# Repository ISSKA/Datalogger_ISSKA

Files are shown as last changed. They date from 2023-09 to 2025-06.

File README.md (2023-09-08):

# ISSKA Datalogger

A Datalogger is a device which controls the sensors and store their values with a given time step. This repository provides the design of several PCBs used for the dataloggers, as well as the codes of the dataloggers.

* The PCB folder contains all the different PCB design used
* The datalogger_code folder contains all the codes for the dataloggers.

For detailed informations about the working principle of a datalogger, code walkthrough and PCB design hints, please refer to the Datalogger Guide PDF.

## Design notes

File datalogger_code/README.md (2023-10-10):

# ISSKA Datalogger codes

This repository contains the different codes used on our dataloggers. There are two Arduino codes for the dataloggers, one for dataloggers with wireless transmission and one for datalogger without wireless transmission. These 2 Arduino codes do not depend on the sensors connected to the datalogger. 

* the simple_datalogger_code is the code with no wireless transmission
* the notecard_datalogger_code is the code with wireless transmission.

There are several different C++ files in the sensors_code folder which are all named Sensors.cpp. For each new sensor configuration, this C++ file must be modified. Refer to the Datalogger Guide pdf for more informations about the Sensors.cpp modifications for a new sensor.

The header file Sensors.h is the same for all codes.

Several different Sensors.cpp code are in the sensors_code folder, for different sensors configurations. All of these codes include the BMP581 and the SHT35 which are already on each PCB. 

## Upload a code on a TinyPico
* select the right Arduino code (wireless transmission or not) and take a Sensors.cpp file in the sensors_code folder for your application or modify one.
* Put the Arduino file (wireless or not), Sensors.cpp file (which you can find in the sensors_code folder) and Sensors.h file in a same folder.
* The folder  must have the name of the arduino file, minus the ".ino"
* Install the needed library on the arduino IDE.
* Connect the TinyPico with your computer and select the right port on Arduino IDE
* Click on the upload button

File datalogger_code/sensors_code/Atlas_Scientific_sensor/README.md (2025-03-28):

# Capteur ATLAS SCIENTIFIC

Les capteurs Atlas Scientific (https://atlas-scientific.com/) présente des particularités 
* I2C et UART. Ils peuvent fonctionner dans les 2 protocoles, mais globalement l'UART est plus robuste. De plus, il faut impérativement bloquer le capteur sur le protocole choisi avec la fonction "Plock,1"
* Il faut d'abord régler le capteur en UART avec le code de base pour les réglages. 

## Autre chose?

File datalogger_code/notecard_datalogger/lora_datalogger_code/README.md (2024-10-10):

# ISSKA Datalogger base code with a notecard LORA
Base code for datalogger with a Notecard connected to the TCA3 of the multiplexer. This code was rewritten in august 2024.

The conf.txt file must have the following structure:
```
300; //time step in seconds (put at least 240 seconds)
1; //boolean value to choose if you want to set the RTC clock with GSM time (recommended to put 1)
12; // number of measurements to be sent at once
```

To modify the time step or the number of measurements to send at once, add these command on the data.qi file of the device on notehub:

* {"time_step":300} ->this sets the time set to 300 seconds
* {"nb_meas":6} ->this sets the number of measurements sent at once to 6

If you have any questions contact me per email at eric.weber@isska.ch

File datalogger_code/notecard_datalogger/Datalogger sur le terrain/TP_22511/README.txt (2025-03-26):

#TP_22511
Installé le 18.05.22 à Milandre Bame avec MS8607 et MS5803-1. Notecard: Not_18
Les données sont envoyées sur le feed Milandre Bame de IoTPlotter

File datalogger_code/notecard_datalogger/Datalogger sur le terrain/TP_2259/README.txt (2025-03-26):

# TP_2259
Installé le 25.05.22 à CISA Anciens Moulins Puits 2 avec MS8607 et MS5803-1. Notecard: Not_20
Les données sont envoyées sur le CISA Anciens moulins de IoTPlotter

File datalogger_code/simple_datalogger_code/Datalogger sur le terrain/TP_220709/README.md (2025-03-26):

# Mesure les varations de la glace à Monlési

Ce datalogger a un capteur PHT MS8607 et deux capteurs de distance.

Capteur 1 : https://www.adafruit.com/product/4664
Capteur 2 : https://www.sparkfun.com/products/retired/14588

Le datalogger a été mis en place le 09.07.22 et l'interval de mesure est d'une heure.

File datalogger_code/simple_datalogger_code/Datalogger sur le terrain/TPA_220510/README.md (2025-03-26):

# TPA_22510
Installé le 11.05.2022 à CISA avec capteur SVM41 et MS8607
Désinstallé qq mois plus tard. 
Le capteur SVM41 n'est pas fonctionnel sous terre. Le temps de préchauffage est trop long.
Ce capteur a été enlevé et le datalogger a seulement le MS8607 pour le moment. 
Modif du RTC faite le 1.11.22 et datalogger renommé en TPA_22510.
Ajouté le capteur BMP581 pour la pression.

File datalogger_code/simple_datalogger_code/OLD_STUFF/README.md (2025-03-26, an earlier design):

# TinyPico Low Power Board
## Explications 
Le dossier TinyPico_datalogger contient le code principal du logger. 
Pour le faire fonctionner il faut ajouter, dans le même dossier que le script principal, les deux fichiers "sensors" qui sont dans les autres dossiers
Ces fichiers permettent de lire les différents capteurs en titre du dossier. 

Il faut donc faire un copier-coller des ces fichiers sensors suivant les capteurs qui se trouvent sur le datalogger. 

!!!ATTENTION!!! Le temps d'execution du code varie suivant les capteurs utilisés. Des corrections de temps peuvent être faites aux lignes 165 et 168 du code principal. Sinon, il est probable que le pas de temps de corresponde pas exactement au pas de temps choisi sur la carte SD.

## Montage
All manufacturing documents are available in the "manufacturing" folder.

### Passive components
TinyPico:
- Mosfet TN0702 : DRAIN on GND, GATE in pin 14 and source on GND rail

### Sensors connected to MUX
All sensors connected to MUX should have pull-ups enabled.

> By default, pull-ups on MS5803-01 are disabled !

## Configuration

### Sensors configuration
Rename file `Sensors.example.cpp` from directory `low_power_board` in `Sensors.cpp` and configure your sensors.

### Pas de temps entre les mesures
Pour définir le pas de temps entre les mesures, ajouter un fichier nommé `conf.txt` à la racine de la carte microSD. Son contenu doit être sous la forme `<pas de temps en secondes>;`, soit `15;` pour un pas de 15 secondes.

## Consommation
Consommation actuelle :
- Environ 150 uA en veille
- Environ 50 mA durant la phase de mesure

Calculateur de durée de fonctionnement : http://www.of-things.de/battery-life-calculator.php.

En prenant en compte que les mesures durent 5 s et qu'on a des pas de mesures de 15 min, la batterie tient environ 460 jours !

## Optimisations possibles
A voir

## Améliorations futures ?
A voir

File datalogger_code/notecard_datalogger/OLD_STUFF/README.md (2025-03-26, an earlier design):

# NoteCard_LTE_DataLogger
Datalogger with a notecard that sends data through LTE
# Description
The notecard sends the data to the notehub platform each time the MAX_MEASUREMENTS number is reached. The data are then routed to another platform called "IoTPlotter". A Python script is available to download the data from this platform.
# Sending of the data
All the data are sent to the notehub through a JSON object. The JSON library used in the arduino notecard library is the "n_cjson" library (available here: https://github.com/blues/note-c/blob/master/n_cjson.c). More explanation of this library and some examples can be found following this link https://github.com/DaveGamble/cJSON.
note: In the second link, cJSON_ is used before all methods. In the first link, this therm is substituted by J.

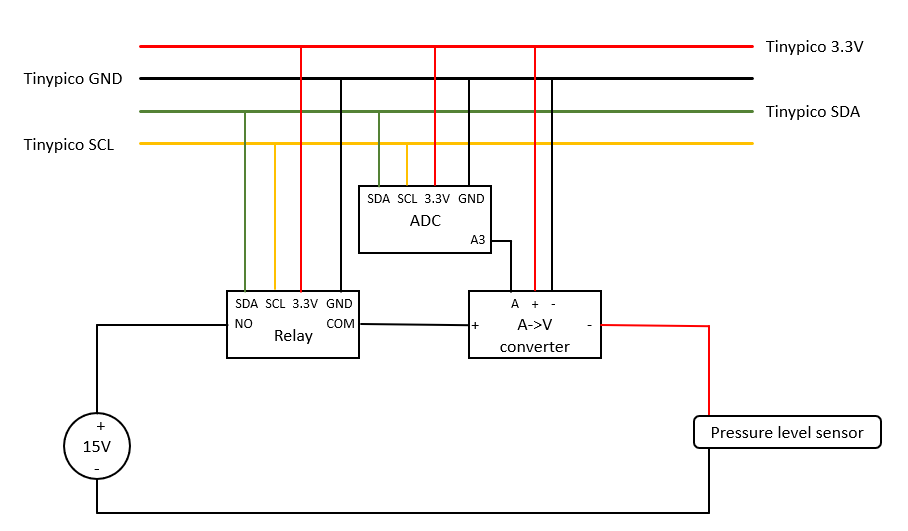
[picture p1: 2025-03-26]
datalogger_code/simple_datalogger_code/Datalogger sur le terrain/TPB_220823/img/schema.png

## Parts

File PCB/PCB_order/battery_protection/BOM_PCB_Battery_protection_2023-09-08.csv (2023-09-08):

ID | Name | Designator | Footprint | Quantity | Manufacturer Part | Manufacturer | Supplier | Supplier Part | Price
1 | 100nF | C3,C4 | C0402 | 2 | CL05B104KB54PNC | SAMSUNG(三星) | LCSC | C307331 | 0.007
2 | 100Ω | R1,R4 | R1206 | 2 | 1206W4F1000T5E | UNI-ROYAL(厚声) | LCSC | C17901 | 0.003
3 | 1kΩ | R2,R3 | R1206 | 2 | 1206W4F1001T5E | UNI-ROYAL(厚声) | LCSC | C4410 | 0.003
4 | DW01_C917079 | U2,U5 | SOT-23-6_L2.9-W1.6-P0.95-LS2.8-BL | 2 | DW01 | JSMSEMI(杰盛微) | LCSC | C917079 | 0.035
5 | 8205A_C5148694 | U3,U4 | TSSOP-8_L4.4-W3.0-P0.65-LS6.4-BL | 2 | 8205A | HXY MOSFET(华轩阳电子) | LCSC | C5148694 | 0.061
6 | BH-18650-B1BA002 | BT1,BT2,BT3 | BATTERY-SMD_18650-1S-L77.1-W20.7-1 | 3 | BH-18650-B1BA002 | MYOUNG(美阳) | LCSC | C2988620 | 1.206

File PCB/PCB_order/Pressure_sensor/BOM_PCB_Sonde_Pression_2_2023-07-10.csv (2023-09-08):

ID | Name | Designator | Footprint | Quantity | Manufacturer Part | Manufacturer | Supplier | Supplier Part | Price
1 | 10uF | C1,C2 | C0805 | 2 | CL21A106KAYNNNE | SAMSUNG(三星) | LCSC | C15850 | 0.011
2 | 10kΩ | R1,R2 | R0805 | 2 | 0805W8F1002T5E | UNI-ROYAL(厚声) | LCSC | C17414 | 0.001
3 | MS5837-02BA | U3 | LGA-4_L3.3-W3.3-P2.00-TL | 1 | MS5837-02BA | null | LCSC | C2887129
4 | AP2112K-3.3TRG1 | U2 | SOT-25-5_L2.9-W1.6-P0.95-LS2.8-BL | 1 | AP2112K-3.3TRG1 | DIODES(美台) | LCSC | C51118 | 0.103

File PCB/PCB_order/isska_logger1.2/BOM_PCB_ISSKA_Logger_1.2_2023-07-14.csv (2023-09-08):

ID | Name | Designator | Footprint | Quantity | Manufacturer Part | Manufacturer | Supplier | Supplier Part | Price
1 | 2.2uF | C1,C6 | C0402 | 2 | CL05A225MQ5NSNC | SAMSUNG(三星) | LCSC | C12530 | 0.003
2 | 10uF | C3,C2 | C1206 | 2 | CL31A106KBHNNNE | SAMSUNG(三星) | LCSC | C13585 | 0.033
3 | 49.9kΩ | R3,R5,R6,R7,R10,R11,R12 | R0402 | 7 | 0402WGF4992TCE | UNI-ROYAL(厚声) | LCSC | C25897 | 0.001
4 | SHT35-DIS-F2.5KS | 0X44 | DFN-8_L2.5-W2.5-P0.50-TL-EP-SHT3X-DIS | 1 | SHT35-DIS-F2.5KS | Sensirion | Digi-Key | 1649-1067-1-ND
5 | BMP581 | 0X46 | BMP581 | 1 | BMP581 | Bosch | Digi-Key | BMP581CT-ND
6 | TCA9548APWR | 0X73 | TSSOP-24_L7.8-W4.4-P0.65-LS6.4-BL | 1 | TCA9548APWR | TI(德州仪器) | LCSC | C130026 | 0.926
7 | CR1220-2ZX | BT1 | BAT-SMD_CR1220-2ZX | 1 | CR1220-2ZX | Q&J | LCSC | C969906 | 0.238
8 | 100uF | C4 | C1206 | 1 | CL31A107MQHNNNE | SAMSUNG(三星) | LCSC | C15008 | 0.062
9 | TF-01A | CARD1 | TF-SMD_TF-01A | 1 | TF-01A | 韩国韩荣 | LCSC | C91145 | 0.175
10 | PowerScrew | CN1 | CONN-TH_XY308-2.54-8P | 1 | XY308-2.54-8P | XINLAIYA(新莱亚) | LCSC | C915917 | 0.741
11 | I2Cscrew | CN2 | CONN-TH_XY308-2.54-8P | 1 | XY308-2.54-8P | XINLAIYA(新莱亚) | LCSC | C915917 | 0.741
12 | QWIIC SENS | CN3,CN4,CN7 | CONN-SMD_X1002WRS-04L-HF-LPSN | 3 | X1002WRS-04L-HF-LPSN | XKB Connectivity(中国星坤) | LCSC | C400341 | 0.11
13 | QWIIC NOT | CN5 | CONN-SMD_X1002WRS-04L-HF-LPSN | 1 | X1002WRS-04L-HF-LPSN | XKB Connectivity(中国星坤) | LCSC | C400341 | 0.11
14 | JST-PH | CN6 | CONN-SMD_P2.00_S2B-PH-SM4-TB-LF-SN | 1 | S2B-PH-SM4-TB(LF)(SN) | JST | LCSC | C295747 | 0.181
15 | 1N4002W | D1,D2 | SOD-123F_L2.8-W1.8-LS3.7-RD | 2 | 1N4002W | 晶导微电子 | LCSC | C169542 | 0.006
16 | OLED | H1 | HDR-TH_4P-P2.54-V-F | 1 | PM2.54-1*4 | ZHOURI(洲日) | LCSC | C5116530 | 0.072
17 | 22uH | L2 | IND-SMD_L3.2-W2.5 | 1 | NLCV32T-220K-EF | TDK | LCSC | C250233 | 0.042
18 | AO3406 | Q1,Q2 | SOT-23-3_L2.9-W1.6-P1.90-LS2.8-BR | 2 | AO3406 | AOS | LCSC | C88051 | 0.112
19 | 10kΩ | R1,R2,R4,R8,R9,R13,R14,R15,R16 | R0805 | 9 | 0805W8F1002T5E | UNI-ROYAL(厚声) | LCSC | C17414 | 0.001
20 | PM254-1-10-Z-8.5 | TINY_LEFT,TINY_RIGHT | HDR-TH_10P-P2.54-V-F | 2 | PM254-1-10-Z-8.5 | HCTL(华灿天禄) | LCSC | C2897373 | 0.152
21 | ME2188C50M5G | U7 | SOT-23-5_L3.0-W1.7-P0.95-LS2.8-BR | 1 | ME2188C50M5G | MICRONE(南京微盟) | LCSC | C236768 | 0.074
22 | NotcardPower | U3 | CONN-TH_DB125-2.54-2P-GN | 1 | DB125-2.54-2P-GN-S | DIBO(地博电气) | LCSC | C918120 | 0.194
23 | RX-TX | U5 | CONN-TH_DB125-2.54-2P-GN | 1 | DB125-2.54-2P-GN-S | DIBO(地博电气) | LCSC | C918120 | 0.194
24 | SCL-SDA | U6 | CONN-TH_DB125-2.54-2P-GN | 1 | DB125-2.54-2P-GN-S | DIBO(地博电气) | LCSC | C918120 | 0.194
25 | 5VPower | U8 | CONN-TH_DB125-2.54-2P-GN | 1 | DB125-2.54-2P-GN-S | DIBO(地博电气) | LCSC | C918120 | 0.194
26 | DS3231SN# | U4 | SOIC-16_L10.3-W7.5-P1.27-LS10.3-BL | 1 | DS3231SN#T&R | MAXIM(美信) | LCSC | C9866 | 3.37

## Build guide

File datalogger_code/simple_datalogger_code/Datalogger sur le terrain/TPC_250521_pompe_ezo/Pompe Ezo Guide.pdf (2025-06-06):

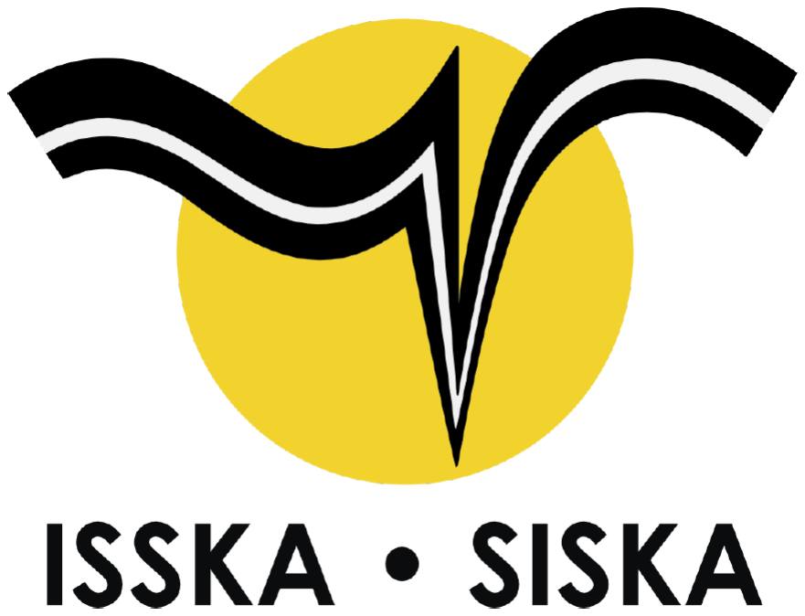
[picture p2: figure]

Swiss Institute for Speleology and Karst Studies

Ezo Pump Integration Guide: Configuration, Usage,

## and Logic

For Automated Dosing Based on Water Height

by

## Marius Audenis

A report made during my civil service at ISSKA, to explain the configuration and usage of the tracer injection pump system and to support future use or modification.

June 02, 2025

## Contents

1 Introduction | 2
2 Setup and Integration | 2
3 Pump Operation Overview | 3
4 Pump Communication Protocol | 4
5 Pump Class Internals | 5

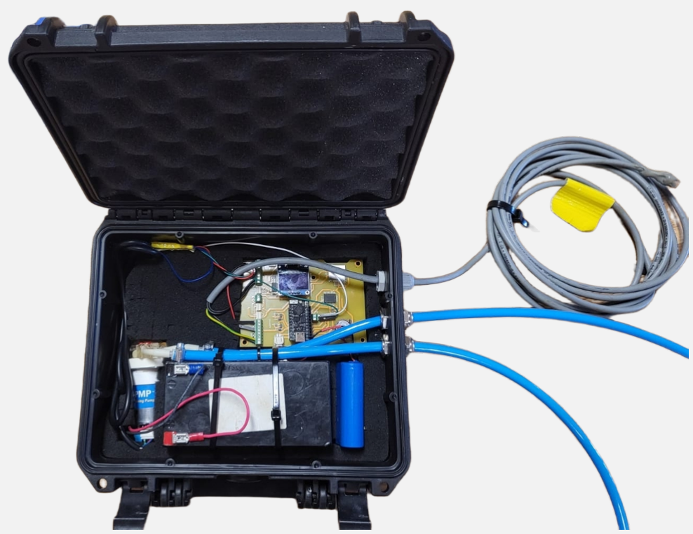
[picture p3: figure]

EZO™ PMP embedded dosing pump integrated with ISSKA datalogger

## 1 Introduction

This guide explains how to integrate and operate the Pump class to control an EZO-PMP™ embed-

ded dosing pump from Atlas Scientific. The class is designed for use on the ISSKA dataloggers code, running on a TinyPICO microcontroller. It automates fluid injection based on measured water heights.

This guide covers physical wiring, configuration files, injection logic, pump communication, and class internals.

## 2 Setup and Integration

### 2.1 Required Files on the SD Card

The pump module relies on two key files stored on the SD card. These files define the injection logic and log pump activity.

- /pump.txt — This file must be added on the datalogger SD card to define injection behavior

and threshold logic.

Each line specifies a water height range, a tracer dose in centimeters, and a maximum number of allowable injections for that range. The format is:

<min_height>-<max_height>,<dose_mL>,<max_injections>;

Example:

30-50,150,2;

50-70,200,1;

This means:

– Inject 150 mL if water height is between 30–50 cm (up to 2 times)

– Inject 200 mL if water height is between 50–70 cm (up to once)

- /pumpdata.csv — Logs pump status and injection history. This file is automatically created

during the pump initialisation and filled at each boot.

Each entry tracks the system boot ID, injection status, and the cumulative number of injections performed. The format is:

<boot_id>;<status>;<cumulative_injections>

Example:

56;Injected;3

57;*OFF;3

Injected indicates an injection occurred during this boot cycle.

*OFF means no injection occurred.

The last field tracks total injections across reboots.

### 2.2 Code Integration Steps

To integrate the Pump class with your datalogger, follow these steps:

1. Include the header and declare the pump object in main.cpp:

#include "Pump.h"

Pump pump;

2. Initialize the pump in setup() after setting up serial communication:

Serial2.begin(9600, SERIAL_8N1, rx, tx);

pump.configure(time_step);

3. Make water height globally accessible in Sensors.cpp (top of file):

float measuredWaterheight = 0.0;

4. Call pump logic after measuring sensors:

measure_all_sensors();

pump.handleInjections2(bootCount, time_step);

## 3 Pump Operation Overview

The pump automates fluid injections depending on water height. The system is designed to inject a specific volume of tracer based on predefined water height classes. Each class corresponds to a range of measured water heights (e.g., 10–20 cm) and is associated with a configurable injection dose (e.g., 5 ml). To ensure balanced tracer distribution, each class also has a limited number of

allowable injections, preventing all the tracer from being delivered within a single height range. All three parameters —the height classes, corresponding doses, and the number of injections— are fully configurable via the system’s configuration file. Also, to maintain injection accuracy, the system enforces cooldown periods between injections (default: 3 hours) to prevent mixing of tracer doses,

which could skew measurement results.

The injection logic is as follows:

1. Maintains a moving average of the last 5 measured water heights.
2. If we are not in a cooldown period (there hasn’t been any injection for more than 3 hours),

it:

- Iterates through doseTable, a variable stored in RTC memory (to survive deepsleep)

containing the height classes, their corresponding injection doses and number of injections.

- If the average water height falls within a defined range and remaining injections for that

class are available:

– Sends a command (e.g., D,150˚) to the pump.

– Enters a cooldown period.

– Decrements the injection count for the corresponding range.

3. If injection is disabled, increments the internal cooldown counter, and once the counter exceeds the threshold (default: every 3 hours), injection is possible again.
4. Logs the current injection status and cumulative injection count to /pumpdata.csv.

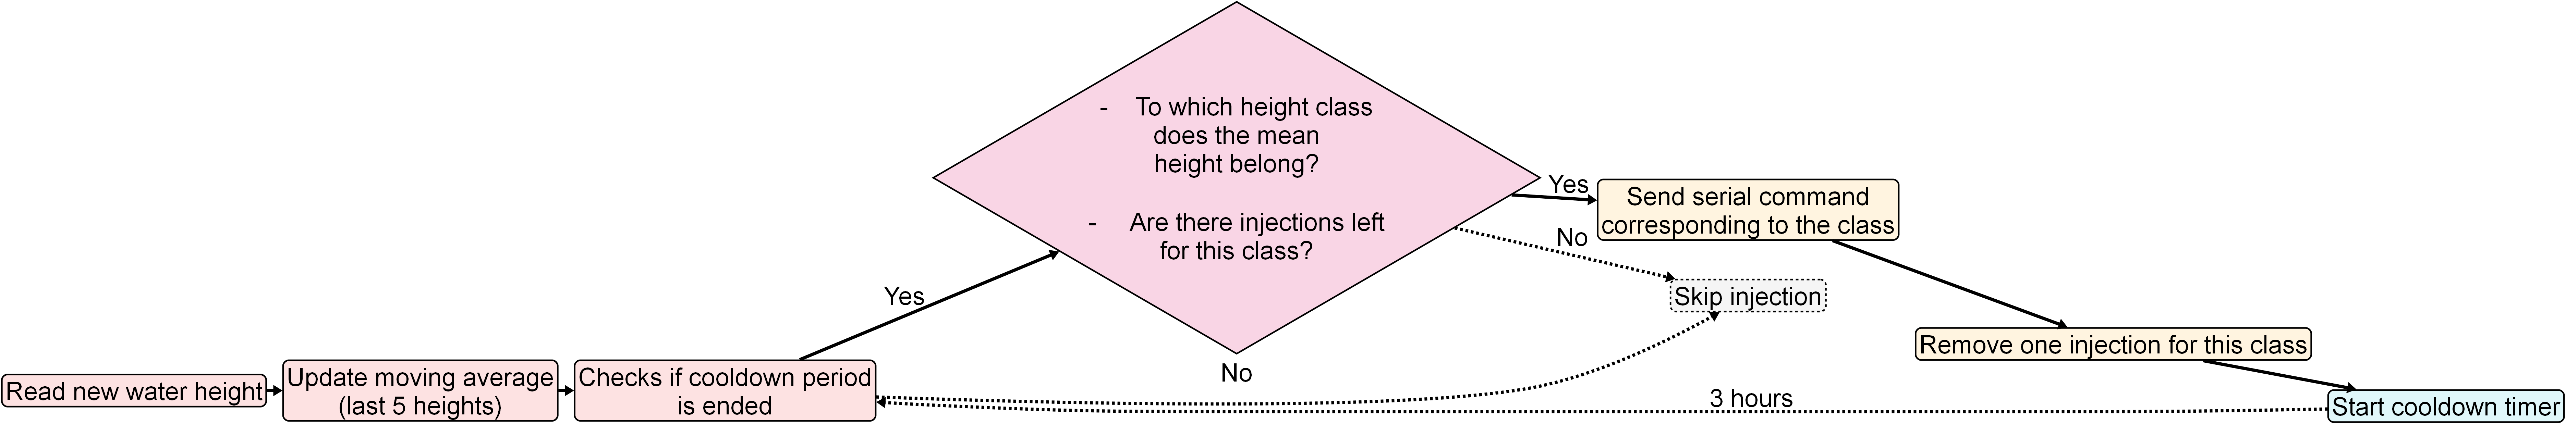
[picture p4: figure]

Figure 1: Schematic workflow of the pump’s logic

## 4 Pump Communication Protocol

The pump communicates over a UART serial interface. All technical details are available in the EZO-PMPTM Embedded Dosing Pump Manual, (https://files.atlas-scientific.com/EZO_PMP_Datasheet.pdf) but key parameters and behaviors are summarized

below:

- Baud rate: 9600
- Command format: D,<dose in mL>\r
- Example command: D,150˚
- Response codes:

– *DONE — Injection completed successfully

– *WA — Injection skipped (already performed)

– *ER — Error occurred during injection

– Timeout — No response received (this one is a custom response added in the code)

## 5 Pump Class Internals

This section explains the internal workings of the Pump class to support customization or debugging.

Core Workflow Functions

configure(int& time step) Initializes the pump system at startup:

- Reads dose rules from /pump.txt and parses them into a class table.
- Sends test signals to verify pump connection.
- Initializes the CSV log with headers.
- Computes boot step based on injection interval.
- Sends an initial test command to the pump.

handleInjections2(int& bootCount, int& time step) Called during each measurement cycle:

- Maintains a moving average over the last 5 water height readings.
- Checks if the current height matches a dosing class.
- Verifies cooldown and injection count limits.
- Sends dose command if permitted.
- Logs the injection result to /pumpdata.csv.

save in SD(int& bootCount) Appends the current injection status and pump count to /pumpdata.csv.

Serial Communication and Pump Control

sendCommand(const String& command) Sends a dosing command to the pump:

- Transmits the command via Serial2 with a carriage return.
- Waits for valid responses: *DONE, *WA, etc.
- Handles errors using handleError() and timeouts.
- Calls pumpSleep() after completion.

readPumpResponse() Reads characters from the serial buffer until a newline or timeout (15 seconds).

- Resets timer on each received byte.

- Returns the trimmed response or Timeout if no response.

handleError(String& response) Interprets and logs error messages:

- Logs *ER or Timeout, and may send a reset command.
- Extracts partial error strings from unknown responses.
- Stores error in latestErrorMessage.

pumpSleep() Sends the Sleep command:

- Waits for *SL confirmation.
- Handles communication errors or timeouts.

Optional Display and Debug Tools

displayConfiguration(U8X8& display) Displays the current dosing table on an OLED screen:

- Shows lower/upper class limits, dose values, and injection counts.
- Pages output every 6 entries to fit screen.

latestErrorMessage A string holding the latest pump response or error (e.g., *DONE, Timeout).

Useful for diagnostics and logging.

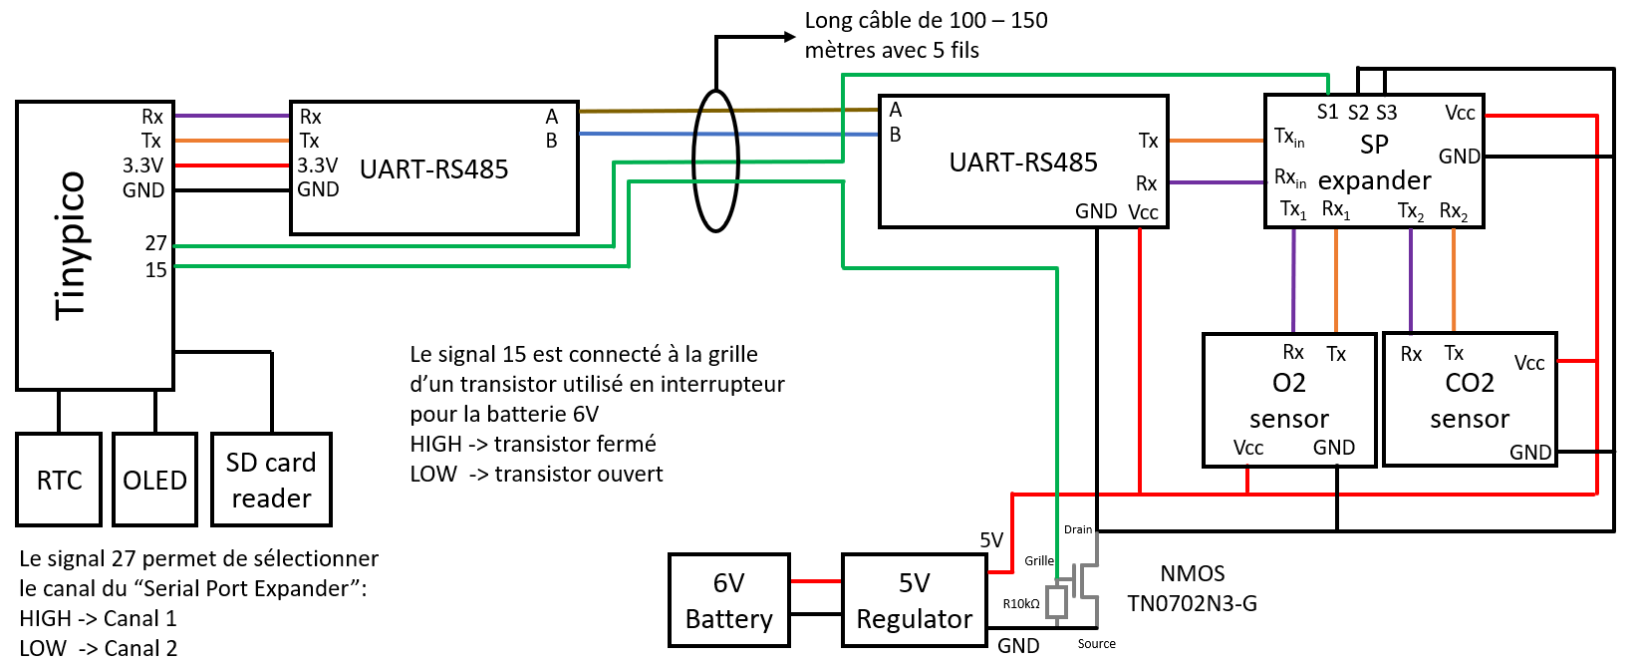
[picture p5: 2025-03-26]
datalogger_code/notecard_datalogger/Datalogger sur le terrain/TP_220921/CO2_O2_RS485/img/MontageV2.png

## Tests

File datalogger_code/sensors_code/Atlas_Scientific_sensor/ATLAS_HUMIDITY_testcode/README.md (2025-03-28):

# Humidité

Pour ce capteur il faut activer la température et le dewPoint avec les fonctions ad-oc sinon il peut arriver qu'il ne mesure que l'humidité

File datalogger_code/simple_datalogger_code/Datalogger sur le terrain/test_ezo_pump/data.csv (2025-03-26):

ID | DateTime | Vbatt | tempSHT | humSHT | tempBMP | pressBMP | flow_rate | tempWater
1 | 31/01/2025 16:15:00 | 4.13 | 28.25 | 27.50 | 27.90 | 908.51 | -0.47 | 22.53
2 | 31/01/2025 16:20:00 | 4.13 | 28.22 | 27.50 | 27.83 | 908.49 | 4.45 | 22.55
3 | 31/01/2025 16:25:00 | 4.14 | 28.24 | 27.38 | 27.82 | 908.51 | -0.16 | 22.60
4 | 31/01/2025 16:30:00 | 4.14 | 28.05 | 27.47 | 27.82 | 908.51 | 3.62 | 22.56
5 | 31/01/2025 16:35:00 | 4.14 | 28.15 | 27.55 | 27.81 | 908.49 | 1.07 | 22.60
6 | 31/01/2025 16:40:00 | 4.13 | 28.25 | 27.48 | 27.83 | 908.48 | 1.09 | 22.56
7 | 31/01/2025 16:45:00 | 4.13 | 28.22 | 27.36 | 27.83 | 908.43 | 6.51 | 22.64
8 | 31/01/2025 16:50:00 | 4.13 | 28.22 | 27.26 | 27.85 | 908.44 | 3.59 | 22.64
9 | 31/01/2025 16:55:00 | 4.13 | 28.28 | 27.34 | 27.83 | 908.49 | 0.39 | 22.58
10 | 31/01/2025 17:00:00 | 4.14 | 28.19 | 27.43 | 27.84 | 908.44 | 1.54 | 22.52
11 | 31/01/2025 17:05:00 | 4.13 | 28.21 | 27.69 | 27.84 | 908.41 | 1.56 | 22.60
12 | 31/01/2025 17:10:00 | 4.13 | 28.31 | 27.50 | 27.82 | 908.36 | -0.28 | 22.56
13 | 31/01/2025 17:15:00 | 4.13 | 28.14 | 27.24 | 27.85 | 908.32 | -0.49 | 22.58
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

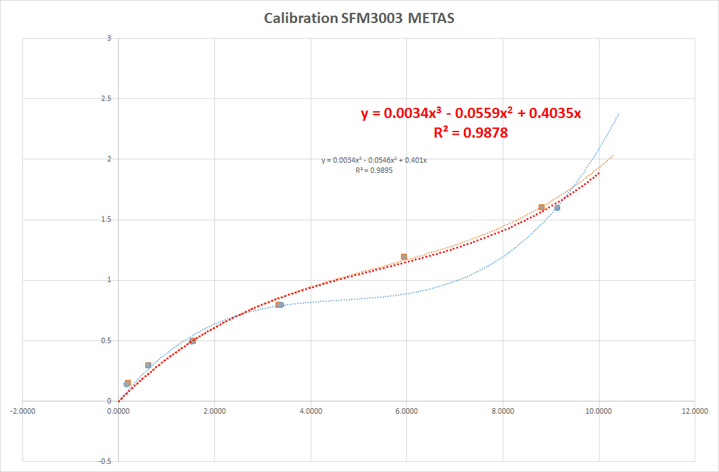
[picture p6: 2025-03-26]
datalogger_code/simple_datalogger_code/Datalogger sur le terrain/TPC_250408_SFM3003_Italie/Calibration_SFM.jpg

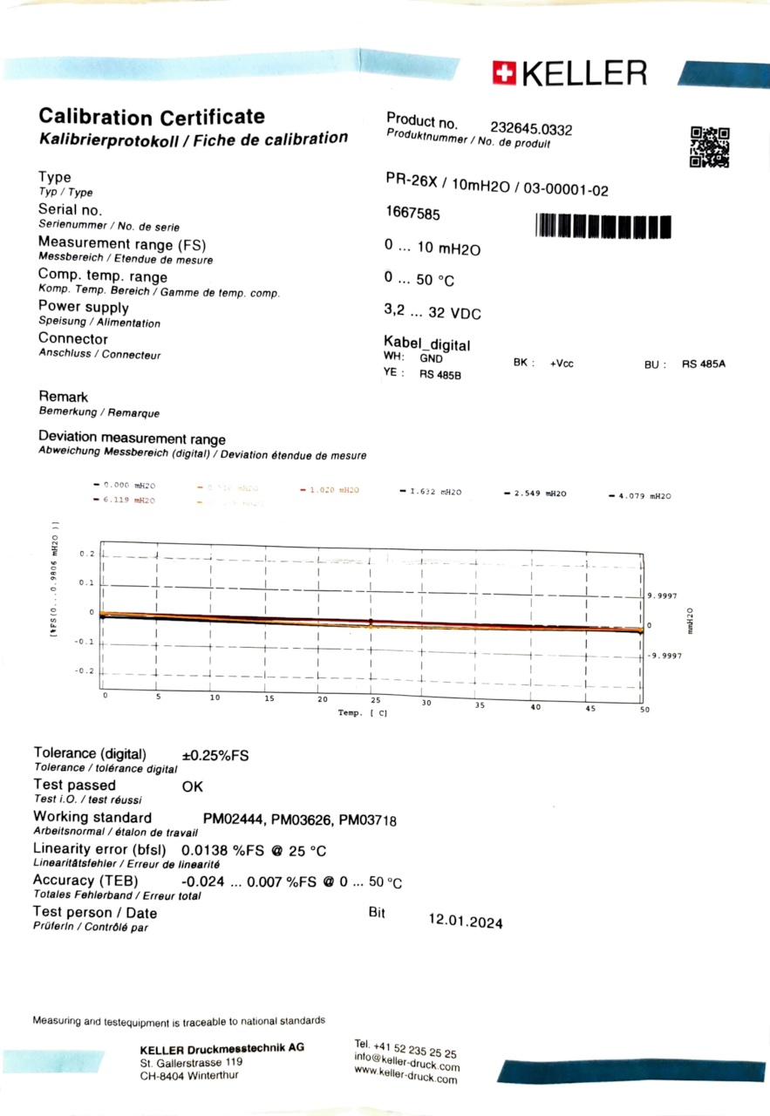
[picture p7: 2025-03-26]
datalogger_code/notecard_datalogger/Datalogger sur le terrain/TPC_240430_Keller_26X_120m/Certificat_calibration_Keller26X.jpg

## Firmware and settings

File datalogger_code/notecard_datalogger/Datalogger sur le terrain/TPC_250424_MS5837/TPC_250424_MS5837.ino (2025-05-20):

/* *******************************************************************************
Base code for datalogger with a Notecard connected to the TCA3 of the multiplexer. This code was rewritten in august 2023.

The conf.txt file must have the following structure:
  300; //time step in seconds (put at least 240 seconds)
  1; //boolean value to choose if you want to set the RTC clock with GSM time (recommended to put 1)
  12; // number of measurements to be sent at once

To modify the time step or the number of measurements to send at once, add these command on the data.qi file of the device on notehub:
{"time_setp":300} ->this sets the time set to 300 seconds
{"nb_meas":6} ->this sets the number of measurements sent at once to 6

If you have any questions contact me per email at nicolas.schmid.6035@gmail.com
**********************************************************************************
*/  

#include <Wire.h>
#include <TinyPICO.h>
#include <RTClib.h>
#include <SD.h>
#include <U8x8lib.h>
#include "Sensors.h" //file sensor.cpp and sensor.h must be in the same folder¨
#include <Notecard.h>

TinyPICO tp = TinyPICO();
RTC_DS3231 rtc; 
U8X8_SSD1306_128X64_NONAME_HW_I2C u8x8(/* reset=*/ U8X8_PIN_NONE); //initialise something for the OLED display
Sensors sensor = Sensors();
Notecard notecard;

//PINS to power different devices
#define Enable5VPIN 25 //turns the 3V to 5V converter on if switched to high
#define MOSFET_SENSORS_PIN 14 //pin which controls the power of the sensors, the screen and sd card reader
#define MOSFET_NOTECARD_PIN 4 //pin which controls the power of the notecard
#define NOTECARD_I2C_MULTIPLEXER_CHANNEL 3 //channel of the multiplexer to which the notecard is connected

#define myProductID "com.gmail.ouaibeer:datalogger_isska" //for the notecard to know with which hub to connect

//SD card
#define SD_CS_PIN 5//Define the pin of the tinypico connected to the CS pin of the SD card reader
#define DATA_FILENAME "/data.csv"
#define CONFIG_FILENAME "/conf.txt"

//Variables which must be stored on the RTC memory, to not be erease in deep sleep (only about 4kB of storage available)
RTC_DATA_ATTR int bootCount_since_change = 0; //boot count since external change from notehub
RTC_DATA_ATTR int bootCount = 0;
RTC_DATA_ATTR bool first_time = true;
RTC_DATA_ATTR int start_time; 
RTC_DATA_ATTR int start_date_time[6]; //[year,month,day,hour,minute,second] of the starting time
RTC_DATA_ATTR int time_step;
RTC_DATA_ATTR int nb_meas_sent_at_once; //number of measurements sent at once with the notecard
RTC_DATA_ATTR bool SetRTC; //read this value from the conf.txt file on the SD card. True means set the clock time with GSM signal
RTC_DATA_ATTR int failed_sync_count = 0;

//********************** MAIN LOOP OF THE PROGRAMM *******************************
//The setup is recalled each time the micrcontroller wakes up from a deepsleep
void setup(){ 

  //Start serial communication protocol with external devices (e.g. your computer)
  Serial.begin(115200);

  power_external_device();

  Wire.begin(); // initialize I2C bus 
  Wire.setClock(50000); // set I2C clock frequency to 50kHz

  if(first_time){ //this snipet is only executed when the microcontroller is turned on for the first time
    tp.DotStar_SetPower(true); //This method turns on the Dotstar power switch, which enables the tinypico LED
    tp.DotStar_SetPixelColor(25, 25, 25 ); //Turn the LED white while SD card is not initialised

    //write Init on the display
    u8x8.begin();
    u8x8.setBusClock(50000); //Give the I2C frequency information to the display
    u8x8.setFont(u8x8_font_amstrad_cpc_extended_r); //set the font
    u8x8.setCursor(0, 0);
    u8x8.print("Init...");
    Serial.println("Init...");

    delay(2000); //wait 2 seconds to see the led and the screen 

    initialise_SD_card(); //read conf.txt file values and store them on RTC memory to access them rapidely, write header on data.csv

    //initialise the RTC clock
    rtc.begin();
    rtc.disable32K(); //The 32kHz output is enabled by default. We don't need it so we disable it
    if (SetRTC) set_RTC_with_GSM_time(); //also gives the number of bars of cellular network (0 to 4) 

    put_usefull_values_on_display(); // show RTC time, battery voltage, time step and sensors values on the display

    get_next_rounded_time(); //this finds the next rounded time and puts it as starting time
    first_time = false; //to make the initialization only once
    deep_sleep_mode(0); //deep sleep until starting time 
  }

  else{ //normal operation (called everytime but not the first time)
    bootCount++; //update how many times we have booted the microcontroller
    bootCount_since_change++; //update how many times we have booted the microcontroller since there was a change of parameters sent from notehub
    Serial.print("***********Starting the card, Boot count: ");
    Serial.print(bootCount);
    Serial.println(" ***********************");

    Serial.print("Boot count since change: ");
    Serial.println(bootCount_since_change);
    Serial.print("Start time: ");
    Serial.println(start_time);
    
    //setup for the clock
    rtc.begin();
    rtc.disable32K(); //The 32kHz output is enabled by default. We don't need it so we disable it
    readRTC();//print current time

    if (bootCount<=3){ //Turn the LED blue during first 3 measurements ( only to check that the logger works normally)
      tp.DotStar_SetPower(true);
      tp.DotStar_SetPixelColor(0, 0, 25 ); 
    }

    mesure_all_sensors();

    if (bootCount_since_change%nb_meas_sent_at_once == 0){ //after a number nb_meas_sent_at_once of measurements, send the last few stored measurements over GSM
      send_data_overGSM();
    }

    if(tp.GetBatteryVoltage()>3.2){
      deep_sleep_mode(time_step);
    }
    else{
      deep_sleep_mode(60*60*24*365*10); //sleep during ten years (don't wake up) to avoid damaging the battery
    }
  }
}

void loop(){ //No loop is used 
}

void power_external_device(){
  //Turn on Pin to control the gate of MOSFET for all the sensors, display and microSD card(turned on)
  pinMode(MOSFET_SENSORS_PIN, OUTPUT);
  digitalWrite(MOSFET_SENSORS_PIN, HIGH);

  //Pin to control the gate of MOSFET for notecard (turned off)
  pinMode(MOSFET_NOTECARD_PIN, OUTPUT);
  digitalWrite(MOSFET_NOTECARD_PIN, LOW);
}

void put_usefull_values_on_display(){
 
  //Display Vattery voltage
  float batvolt = tp.GetBatteryVoltage();
  u8x8.display(); // Power on the OLED display
  u8x8.clear();
  u8x8.setCursor(0, 0);
  u8x8.print("Batt: ");
  u8x8.print(batvolt);
  u8x8.print("V");

  //Display current time on RTC
  u8x8.setCursor(0, 2);
  u8x8.print(readRTC());

  //Display value of timestep read on conf.txt
  u8x8.setCursor(0, 4);
  u8x8.print("timestep: ");
  u8x8.print(time_step);
  u8x8.print("s");

  //Display value of nuber of measurements to be sent at once read on conf.txt
  u8x8.setCursor(0, 6);
  u8x8.print("Nb meas: ");
  u8x8.print(nb_meas_sent_at_once);

  delay(4000);

  //Display sensor values
  sensor.measure();   //measure all sensors
  String measured_values_str = sensor.serialPrint();
  u8x8.clear();
  u8x8.setCursor(0, 0);
  int line_count = 0;
  for (char const &c: measured_values_str) {
    if(c=='\n'){
      line_count++;
      if (line_count%8 ==0){ //if we have more than 8 sensors to display and there is no more space on the screen
        delay(8000);
        u8x8.clear();
        u8x8.setCursor(0, 0);
      }
      else u8x8.println();
    }
    else u8x8.print(c);
  }
  delay(8000); //wait 8 seconds to see the values on the display
}

void get_next_rounded_time(){ 
  //The computation of the starting time only works if the time step is either less than 60 or a multiple of 60 otherwise we will have an unexpected behaviour.

  DateTime current_time=rtc.now(); //get current time
  int seconds_remaining = 60-current_time.second()%60;  //compute the number of seconds left until the next rounded minute (where seconds is :00)
  DateTime time_seconds_rounded_up = current_time+seconds_remaining;

  DateTime start_datetime;
  if(time_step<60){ 
    start_datetime = time_seconds_rounded_up;
  }
  else{ //time_step>=60
    int rounded_min = time_step/60; //gives the time step in minute
    if(time_seconds_rounded_up.minute()%rounded_min==0){
      start_datetime = time_seconds_rounded_up; //minute already multiple of time_step
    }
    else{ //compute the number of minutes until the next rounded time (in minutes)
      int minutes_remaining = rounded_min - time_seconds_rounded_up.minute()%rounded_min; 
      start_datetime = (time_seconds_rounded_up + 60*minutes_remaining);
    }
  }
  //we store the start_time in RTC memory, but since a DateTime type cannot be stored in RTC we store it as unixtime, and store the year, month, day, hour, minute and seconds in an array
  start_time = start_datetime.unixtime(); 
  start_date_time[0]=start_datetime.year();
  start_date_time[1]=start_datetime.month();
  start_date_time[2]=start_datetime.day();
  start_date_time[3]=start_datetime.hour();
  start_date_time[4]=start_datetime.minute();
  start_date_time[5]=start_datetime.second();
  Serial.print("start time: ");
  Serial.println(start_datetime.timestamp(DateTime::TIMESTAMP_FULL));
}

void initialise_SD_card(){ //open SD card. Write header in the data.csv file. read values from the conf.txt file.
  bool SD_error = false;
  if (!SD.begin(SD_CS_PIN)) { //initialisation, do this snipet of code only if initialization fails
    Serial.println("SD card initialization failed!");
    SD_error = true;
  }
  else{ //Do this snipet of code only if initialization is a success
    File configFile = SD.open(CONFIG_FILENAME);
    if (configFile.available()) {

      //read time step
      time_step = configFile.readStringUntil(';').toInt();
      while (configFile.peek() != '\n'){ //if there are any black space if the config file
        configFile.seek(configFile.position() + 1);
      }
      configFile.seek(configFile.position() + 1); //to remove the \n character itself

      //read setRTC bool value
      String str_SetRTC = configFile.readStringUntil(';');
      if (str_SetRTC=="0") SetRTC = false;
      else if (str_SetRTC=="1") SetRTC = true;
      else {
        Serial.println("problem by reading the SetRTC value from SD card");
        SD_error = true;
      }
      while (configFile.peek() != '\n'){ //if there are any black space if the config file
          configFile.seek(configFile.position() + 1);
      }
      configFile.seek(configFile.position() + 1); //to remove the \n character itself

      //read number of measurement to be sent at once
      String str_nb_meas_sent_at_once = configFile.readStringUntil(';');
      nb_meas_sent_at_once = str_nb_meas_sent_at_once.toInt();
    }
    configFile.close();

    //print values read on the conf.txt file
    Serial.println("Values read from SD Card:");
    Serial.print("- Deep sleep time: ");
    Serial.println(time_step);
    Serial.print("- Set the RTC clock with GSM: ");
    Serial.println(SetRTC);
    Serial.print("- Number of measurements to be sent at once: ");
    Serial.println(nb_meas_sent_at_once);
  }

  //display error or success message, wether ther was an error or not
  u8x8.setCursor(0, 2);
  if (SD_error == true){
    u8x8.print("SD Failure !");
    tp.DotStar_SetPixelColor( 50, 0, 0 ); //set led to red
  }
  //write header in SD
  else {
    File dataFile = SD.open(DATA_FILENAME, FILE_APPEND);
    String header = sensor.getFileHeader();
    dataFile.println();
    dataFile.println();
    dataFile.println();
    dataFile.print("ID;DateTime;");
    dataFile.println(header);
    dataFile.close();
    // show on display and LED if values on SD card are OK
    u8x8.setCursor(0, 2);
    u8x8.print("Success !");
    tp.DotStar_SetPixelColor( 0, 50, 0 );
  }
  delay(1000); //in [ms] in order to see the LED and the success message
}

void deep_sleep_mode(int sleeping_time){ 
  //turn off all things that might consume some power
  digitalWrite(MOSFET_SENSORS_PIN, LOW);
  digitalWrite(MOSFET_NOTECARD_PIN, LOW);
  tp.DotStar_SetPower(false); //LED of the TinyPico
  rtc.writeSqwPinMode(DS3231_OFF);
  //set alarm on RTC
  rtc.clearAlarm(1); //to clear a potentially previously set alarm set on alarm1
  rtc.disableAlarm(2); //disable alarm2 to ensure that no previously set alarm causes any problem
  rtc.setAlarm1(start_time+bootCount_since_change*sleeping_time,DS3231_A1_Hour);  
  pinMode(GPIO_NUM_15, INPUT_PULLUP);
  //specify wakeup trigger and enter deep sleep
  esp_sleep_enable_ext0_wakeup(GPIO_NUM_15, 0); //2nd param. is logical level of trigger signal (tinypico is wake-up when signal is low in this case)
  esp_deep_sleep_start();
}

String readRTC() { //print current time
  DateTime now = rtc.now();
  String time_str = String(now.day()) + "/" + String(now.month()) + " " + String(now.hour())+ ":" + String(now.minute()) + ":" + String(now.second());
  Serial.print("Current time: ");
  Serial.println(time_str);
  return time_str;
}

void save_data_in_SD(){ 
  //put the measured values in a string with the following format: "ID;DateTime;VBatt;tempEXT;pressEXT;HumExt;..." 
  String data_message = (String) bootCount;
  char buffer [35] = "";
  DateTime starting_time_dt = DateTime(start_date_time[0],start_date_time[1],start_date_time[2],start_date_time[3],start_date_time[4],start_date_time[5]);
  DateTime curr_time = starting_time_dt +(bootCount_since_change-1)*time_step;
  sprintf(buffer, "%02d/%02d/%04d %02d:%02d:%02d", curr_time.day(), curr_time.month(), curr_time.year(), curr_time.hour(), curr_time.minute(), curr_time.second());
  data_message = data_message + ";"+ buffer + ";";
  String sensor_data = sensor.getFileData(); 
  data_message = data_message + sensor_data;
  Serial.println(data_message);

  //initialise SD card
  if (!SD.begin(SD_CS_PIN)) { //if there is a problem with the SD card turn on display to show to the user that there is a problem with the SD card
    Serial.println("SD card initialization failed!");
    u8x8.begin();
    u8x8.setBusClock(50000);
    u8x8.setFont(u8x8_font_amstrad_cpc_extended_r);
    u8x8.setCursor(0, 0);
    u8x8.print("SD Failure !");
    tp.DotStar_SetPower(true);
    tp.DotStar_SetPixelColor( 50, 0, 0 ); //set led to red
    delay(5000); //in [ms] in order to see the LED and display because there is an important and recurent error 
  }
  else{ //if there is no error with the SD card store the data message
    File dataFile = SD.open(DATA_FILENAME, FILE_APPEND);
    dataFile.print(data_message);
    dataFile.println();
    dataFile.close();
  }
}

void mesure_all_sensors(){
  Serial.println("Start of the measurements");
  sensor.measure(); // measures all sensors and stores the values in an array
  sensor.serialPrint(); //print all the sensors' values in Serial monitor
  save_data_in_SD(); //save measuremetns on the SD card
}

void initialize_notecard(){
 //power the notecard and switch the multiplexer to its I2c line
  digitalWrite(MOSFET_NOTECARD_PIN, HIGH); 
  sensor.tcaselect(NOTECARD_I2C_MULTIPLEXER_CHANNEL);
  delay(100);

  //start notecard
  notecard.begin();
  delay(400);

  //set the notecard mode and tell where to send data
  J *req_set = notecard.newRequest("hub.set");    
  JAddStringToObject(req_set, "product", myProductID);
  JAddStringToObject(req_set, "mode", "minimum");
  notecard.sendRequest(req_set);
}

bool synchronize_notecard(){ //returns true if it was able to connect the notecard to GSM nework
  //send command to sync the notecard
  notecard.sendRequest(notecard.newRequest("hub.sync"));
  //wait for syncronisation
  bool GSM_time_out = false;
  unsigned long start_time_connection = micros();
  int completed=0;
  do{ //this loop wait until then connection is completed or until we reach 4 minutes (timeout)
    J *SyncStatus = notecard.requestAndResponse(notecard.newRequest("hub.sync.status"));
    completed = (int)JGetNumber(SyncStatus,"completed");
    notecard.deleteResponse(SyncStatus); //delete the response
    if((micros()-start_time_connection)/1000000>120){ //after 240s stop waiting for the connexion
      GSM_time_out = true;
      return false;
    }
    delay(500); //check connection status every 500ms
  } while (completed==0 && !GSM_time_out); 

  if (completed!=0){
    Serial.println("The notecard is syncronized!");
    return true;
  }
  else{
    Serial.println("The notecard failed to synchronize!");
    return false;
  }
}

void get_external_parameter(){   //get parameters from notehub like timestep or nb_meas
  //get the number of changes made on notehub
  J *notecard_changes = notecard.requestAndResponse(notecard.newRequest("file.changes"));
  J *changes_infos = JGetObjectItem(notecard_changes,"info");
  J *data_changes = JGetObjectItem(changes_infos,"data.qi");
  int nb_changes = (int) JGetInt(data_changes,"total");
  notecard.deleteResponse(notecard_changes);
  Serial.print("Nb Changes: ");
  Serial.println(nb_changes);
  int new_time_step = 0;
  int new_nb_meas_sent_at_once = 0;

  if (nb_changes >0){ // only do something if there were changes on notehub
    while (nb_changes>0){
      //the parameters changed come in a FIFO queue, so oldest changes comes first in this loop and can later be overwritten by new changes if there were sevral changes of the same parameter
      J *req = notecard.newRequest("note.get"); 
      JAddStringToObject(req, "file", "data.qi"); 
      JAddBoolToObject(req, "delete", true);
      J *parameter_changed = notecard.requestAndResponse(req);
      J *parameter_changed_body = JGetObjectItem(parameter_changed,"body");

      //adjust the correct parameter depending on its name
      int temp_time_step = (int) JGetInt(parameter_changed_body,"time_step"); 
      if(temp_time_step != 0){
        new_time_step = temp_time_step;
      }
      int temp_nb_meas_sent_at_once = (int) JGetInt(parameter_changed_body,"nb_meas");
      if(temp_nb_meas_sent_at_once != 0){
        new_nb_meas_sent_at_once = temp_nb_meas_sent_at_once;
      }
      notecard.deleteResponse(parameter_changed);
      nb_changes-=1;
    }
    if(new_time_step!=0 || new_nb_meas_sent_at_once!=0){ //only do changes if one of the parameters changed on notehub had the correct name
      if(new_time_step==0) new_time_step = time_step; //no change in time step
      if(new_nb_meas_sent_at_once==0) new_nb_meas_sent_at_once = nb_meas_sent_at_once; //no change in nb_meas_sent_at_once
      Serial.print("new time step: ");
      Serial.println(new_time_step);
      Serial.print("new number of measurements to send at once: ");
      Serial.println(new_nb_meas_sent_at_once);
      synchronize_notecard(); //sync the fact that we read and deleted parameters to remove them from the notehub queue

      //write changes to sd card conf.txt file
      Serial.println("change conf file");
      String new_conf_file_str = String(new_time_step)+"; //time step in seconds \n";
      new_conf_file_str = new_conf_file_str + String(SetRTC) +"; //set RTC with GSM time (1 or 0) \n";
      new_conf_file_str = new_conf_file_str + String(new_nb_meas_sent_at_once) +"; //number of measurements to be sent at once via gsm \n";
      SD.remove(CONFIG_FILENAME); //delete conf file
      File configFile = SD.open(CONFIG_FILENAME, FILE_APPEND); //create a new conf file with new parameters
      configFile.print(new_conf_file_str);
      configFile.close();

      if(bootCount!=0){
        //since we might have changed the time step, the computation of the wake up time: wkae_up_time = start_time + bootcount_since_change * time_step no longer holds
        //the solution is to redefine the start time with the next wakeup time and to set the bootcount since change to 0
        DateTime starting_time_dt = DateTime(start_date_time[0],start_date_time[1],start_date_time[2],start_date_time[3],start_date_time[4],start_date_time[5]);
        DateTime new_start_time = starting_time_dt +bootCount_since_change*time_step;
        start_time = new_start_time.unixtime();
        start_date_time[0]=new_start_time.year();
        start_date_time[1]=new_start_time.month();
        start_date_time[2]=new_start_time.day();
        start_date_time[3]=new_start_time.hour();
        start_date_time[4]=new_start_time.minute();
        start_date_time[5]=new_start_time.second();
        bootCount_since_change = 0;
      }
      time_step=new_time_step;
      nb_meas_sent_at_once=new_nb_meas_sent_at_once;
    }
  }
}

void set_RTC_with_GSM_time(){ //gets the time from GSM and adjust the rtc clock with the swiss winter time (UTC+1)
  Serial.println("Try to use the notehub to request the GSM time ....");
  unsigned int GSM_time = getGSMtime()+2; // I added an offset of 2 seconds since the time was somehow always off by 2 seconds
  rtc.adjust(DateTime(GSM_time));  
  readRTC();
  sleep(3);
}
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

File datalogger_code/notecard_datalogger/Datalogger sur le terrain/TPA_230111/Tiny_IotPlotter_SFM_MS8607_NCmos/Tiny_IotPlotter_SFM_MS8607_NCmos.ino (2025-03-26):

//Code version du 26.04.2022 avec Tstep en seconde
//Un MOSFET est utilisé pour alimenter la notecard seulement lors de l'envoi
//050422: Add connection after first measurement & Set time of RTC with notecard time after each reset
#define SERIAL_DEBUG true
// Allow to display each mesures done to the OLED display (should be disabled for production)
#define ALWAYS_DISPLAY_TO_OLED false
// microSD
#include <SPI.h>
#include <SD.h>
#include <Wire.h>
//#include "WiFi.h"
#include "driver/adc.h"
//#include <esp_wifi.h>
//#include <esp_bt.h>
#include <Notecard.h>
#define myProductID "com.gmail.ouaibeer:datalogger_isska"
#define NOTECARD_I2C_ADDRESS 0x17
Notecard notecard;
//Include libraries for multidimensional arrays
#include <cstring>
#include <CSV_Parser.h>
#include <U8x8lib.h>
#define SCL_PIN 22
#define SDA_PIN 21
// sensors
#include "Sensors.h"
#include <RTClib.h>

#define RTC_PIN 27
#define YEAR(y) y + 1970
#define MOSFET_PIN 14
#define MOSFET_NOTECARD_PIN 4

#include <string.h>
#include <stdio.h>
//Short filename of the current code running
#define __FILENAME__ (strrchr(__FILE__, '\\') ? strrchr(__FILE__, '\\') + 1 : __FILE__)

//Define CS pin for the SD card module
#define SD_CS 5

//SD card
#define DATA_FILENAME "/data.csv"
#define CONFIG_FILENAME "/conf.txt"
#define uS_TO_S_FACTOR 1000000
String dataMessage;
float batvolt;


RTC_DS3231 RTC;
/***************************************************************
   Variables
 ***************************************************************/
U8X8_SSD1306_128X64_NONAME_HW_I2C u8x8(/* reset=*/ U8X8_PIN_NONE, SCL_PIN, SDA_PIN);

//#define SENDING_TIME_MS 180*1000
// DS3231
time_t wakeUpInterval = 1 * 60; //in sec, here: 10min
unsigned int Sending_time_ms = 180 * 1000;
boolean SetRTC = true;

boolean firstRun = true;
// sensors
Sensors sensors;

#include <TinyPICO.h>
TinyPICO tp = TinyPICO();

// Save reading number on RTC memory
RTC_DATA_ATTR unsigned int readingID = 0;
RTC_DATA_ATTR unsigned int measurementSendingThreshold = MAX_MEASUREMENTS;
//Array of arrays in which the last measurements are saved before sending this latter on the server
RTC_DATA_ATTR float LastMeasurements[MAX_MEASUREMENTS][Nb_values_sensors + 2] = {};
//here 2 is for ID;VBatt;+number of values given by the sensors (defined in sensor.h)
RTC_DATA_ATTR char SavedDates[MAX_MEASUREMENTS][25];
RTC_DATA_ATTR unsigned int DatesUNIX[MAX_MEASUREMENTS];
// each int and float takes 4 bytes, a char = 1 bytes
//Example with MAX_MEASUREMENTS = 24 and Nb_values_sensors = 6
// Bytes: 2*4 + 192*4 + 600*1 + 24 * 4= 1472 bytes = 1,47 KB
// The available memory is around 8 KB and maybe the half 4KB




void setup()
{
  //Start the ADC conversion https://docs.espressif.com/projects/esp-idf/en/latest/esp32/api-reference/peripherals/adc.html
  adc_power_acquire();
  Serial.begin(115200);
  //Set the SCL at 50kHz since we can have long cables in some cases
  Wire.begin();
  Wire.setClock(50000);
  tp.DotStar_SetPower(true);
  pinMode(RTC_PIN, OUTPUT);         // RTC and status LED power via pin D7 (about 3 mA)
  digitalWrite(RTC_PIN, HIGH);      // Switch DS3231 RTC Power and Status LED on - Switched off in ESP12 Deep Sleep mode
  pinMode(MOSFET_PIN, OUTPUT);
  digitalWrite(MOSFET_PIN, HIGH);
  //Pin to control the gate of MOSFET for notecard
  pinMode(MOSFET_NOTECARD_PIN, OUTPUT);
  digitalWrite(MOSFET_NOTECARD_PIN, LOW);


  // SD optimization
  // https://github.com/EKMallon/UNO-Breadboard-Datalogger/blob/master/_20160110_UnoBasedDataLogger_v1/_20160110_UnoBasedDataLogger_v1.ino
  // Setting the SPI pins high helps some sd cards go into sleep mode
  pinMode(SD_CS, OUTPUT); digitalWrite(SD_CS, HIGH); // ALWAYS pullup the ChipSelect pin with the SD library
  pinMode(MOSI, OUTPUT); digitalWrite(MOSI, HIGH); // pullup the MOSI pin
  pinMode(MISO, INPUT_PULLUP); // pullup the MISO pin
  delay(10);

  // Wait for system voltage regulation
  tp.DotStar_SetPixelColor( 44, 65, 203 );
  sleep(2);
  if (readingID == 0) {
    firstRun = true;
  }
  else {
    firstRun = false;
  }

  // Initialisation du OLED
  if (firstRun || ALWAYS_DISPLAY_TO_OLED) {
    //Set the SCL at 50kHz since we can have long cables in some cases
    //Otherwise, the OLED set the frequency at 500kHz
    u8x8.setBusClock(50000);
    u8x8.begin();
    u8x8.setFont(u8x8_font_amstrad_cpc_extended_r);
    //u8x8.setContrast(0);
    //u8x8.clear();
    u8x8.setCursor(0, 0);
    u8x8.print(F("Init..."));
  }

  // see if the card is present and can be initialized:
  SD.begin(SD_CS);
  if (!SD.begin(SD_CS)) {
    Serial.println(F("Card Mount Failed"));
    u8x8.setCursor(0, 2);
    u8x8.print(F("SD Init Error!"));
    tp.DotStar_SetPixelColor( 255, 0, 0 );

    // Enter sleep mode
    sleep(4);
    u8x8.noDisplay();
    deep_sleep_mode(wakeUpInterval);
    // while(1);
  }
  delay(25); //SD.begin hits the power supply pretty hard

  if (firstRun) {
    if (!writeFileHeader()) {
      u8x8.setCursor(0, 2);
      u8x8.print(F("SD Write Error!"));

      // Enter sleep mode
      sleep(4);
      u8x8.noDisplay();
      deep_sleep_mode(wakeUpInterval);
      // while(1);
    }
  }
  // read step config
  int steps = readConfigFile();
  if (steps > 0) {
    wakeUpInterval = steps;
  }
  Serial.print("Measurement step [s]:");
  Serial.println(wakeUpInterval);
  // sensors init
  //sensors.setup();
  // display to Oled only at the starting
  if (firstRun || ALWAYS_DISPLAY_TO_OLED) {
    u8x8.setCursor(0, 2);
    u8x8.print(F("Success !"));
    tp.DotStar_SetPixelColor( 0, 255, 0 );
    sleep(2);
    tp.DotStar_Clear();
  }
  //we don't need the 32K Pin, so disable it
  //32K pin is the frequency signal of the RTC (32KHz)
  if (! RTC.begin()) {
    Serial.println(F("Couldn't find RTC"));
    Serial.flush();
    abort();
  }
  RTC.disable32K();
  batvolt = tp.GetBatteryVoltage();
  //If it's the first run, the RTC time is set by requesting the time to the notecard
  if (firstRun && SetRTC)
  {
    Serial.println("Connection to the notehub to request the time ....");
    Serial.println("Status of the connection is checked each 10 seconds.");
    //Connection of the notecard to the notehub
    InitializeNoteHubConnection();
    //Request of the notecard time
    unsigned int RecievedTime = 0;
    String TimeZoneRecieved;
    J *rsp = notecard.requestAndResponse(notecard.newRequest("card.time"));
    if (rsp != NULL) {
      RecievedTime = (unsigned int)JGetNumber(rsp, "time");
      TimeZoneRecieved = (String)JGetString(rsp, "zone");
      notecard.deleteResponse(rsp);
    }
    //Turn off the notecard
    digitalWrite(MOSFET_NOTECARD_PIN, LOW);
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

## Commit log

2023-09-08 new repository with all new datalogger stuff
    [BOM_PCB_ISSKA_LOGGER_TINY_1.0_2023-07-28.csv, BOM_PCB_ISSKA_Logger_1.2_2023-07-14.csv, BOM_PCB_Sonde_Pression_2_2023-07-10.csv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]
2023-09-08 new sensors code
    [BOM_PCB_Battery_protection_2023-09-08.csv, PickAndPlace_PCB_Battery_protection_2023-09-08.csv]
2023-09-25 Modif battery level shut down
    L'arrêt total à 3.5v est trop radical. De plus, on ne veut pas couper complétement les mesures.
2024-08-12 somes new
    [Calibration_data.xlsx]
2024-11-12 Mauvais pin pour le 5v
2025-03-26 Moved from old repo to new one
    [Calibration_data.xlsx, PrixPieces.csv, SFM_Conversion curve & Uncert.xlsx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]
2025-03-26 Déplacement des datalogger terrain notecard
    [SFM_Conversion curve & Uncert.xlsx]
2025-04-09 Datalogger pour Italie PYJ
    [SFM_Conversion curve & Uncert.xlsx]
2025-05-23 changement de capteur O2 donc de facteur de correction
